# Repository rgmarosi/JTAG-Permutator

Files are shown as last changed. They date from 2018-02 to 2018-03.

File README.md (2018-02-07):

# JTAG-Permutator
A low-cost USB tool for identifying pinouts of possible JTAG programming/debug interfaces on electronics.
<p align="center">
  
  
  
</p>

## License
The JTAG Permutator is an adaptation of the "[JTAGulator](https://github.com/grandideastudio/jtagulator)" designed by Joe Grand of [Grand Idea Studio](http://www.grandideastudio.com/) and is used under the [Creative Commons Attribution 3.0 United States license](https://creativecommons.org/licenses/by/3.0/us/).

The JTAG Permutator design is also distributed under the [Creative Commons Attribution 3.0 United States license](https://creativecommons.org/licenses/by/3.0/us/).

### Major changes from the JTAGulator design
1. Silicon Labs EFM8 microcontroller used instead of Parallax microcontroller with USB-UART bridge IC
2. Target voltage supplied by SC195 buck regulator rather than filtered PWM
3. Removed screw terminals
4. Reduced IO channels from 24 down to 8
5. Used different level translator IC (target voltage range is now 0.8V~3.3V) (to be verified)
6. Reduced board area from 13.6 square inches down to 1.7 square inches

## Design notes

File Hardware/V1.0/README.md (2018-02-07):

# Notes
- IDC headers are not placed in BOM because fab & assembly is cheaper with all SMD components. They can be easily hand-soldered.
- The JTAG Permutator is compatible with [Bus Pirate V3 probes](https://www.seeedstudio.com/Bus-Pirate-v3-probe-Kit-p-526.html) or equivalent.
- The programmer interface requires a stronger 1kOhm pull-up resistor on the reset pin in order for the debug adapter to remain connected to the JTAG Permutator
  - Solder a 1kOhm resistor between TP1 and TP5 on the rear of the board to fix this
- The programmer used with the programmer header is the Silicon Labs [8-bit USB Debug Adapter](https://www.silabs.com/products/development-tools/mcu/8-bit/8bit-mcu-accessories/8-bit-debug-adapter)
  - The programmer header may not be needed if I can figure out how to use the bootloader on the EFM8. Until then, it's there for easy debugging of this first prototype.
- The fab & assembly house I used for this first prototype was [MacroFab](https://macrofab.com/). Another good self-serve fab & assembly house is [PCB:NG](https://www.pcb.ng/).
- I don't yet know if the onboard buck regulator (SC195) output is tri-stated when disabled. I need to test it. For now, don't connect the target power rail to powered targets. Only use it if you're powering the target using the JTAG Permutator.
  - Maximum current output of the buck regulator is ~500mA.
## Pull-up resistor fix
<p align="left">
  
</p>

# Planned changes
1. Pull up C2CK pin of microcontroller to 5V rail using 1kOhm resistor.
2. Remove programming header once bootloader is figured out and firmware is functioning as intended. Keep C2 interface and power rail test points.
3. Add silkscreen pin table for probe cable if space permits.
4. More to come...

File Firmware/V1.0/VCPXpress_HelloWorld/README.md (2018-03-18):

Prints "Hello World!" to a serial console every half second and blinks the "Heartbeat" LED on the board every second.

Have either the [Silicon Labs VCP Drivers](https://www.silabs.com/products/development-tools/software/usb-to-uart-bridge-vcp-drivers) installed on your PC, or have Simplicity Studio IDE installed on your PC to allow communication between your serial terminal and the microcontroller. Any serial terminal configuration should work.

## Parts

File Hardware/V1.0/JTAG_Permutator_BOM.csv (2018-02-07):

Title | JTAG Permutator
Revision | 1
Date | 2/6/2018
Generated | 2/6/2018 16:55
Company
Comment 1 | Robert Marosi
Comment 2 | CC BY 3.0 US
Comment 3
Comment 4
Total Parts | 43
Total Unique Parts | 20
Ref | Qty | Value | Footprint | MFR | MPN | SPN | SPR | DNI
C7 | 1 | 10uF | Capacitors_SMD:C_0603 | TDK Corporation | C1608X5R0J106M080AB | 445-4112-2-ND | Digi-Key
C6 C3 C1 | 3 | 4.7uF | Capacitors_SMD:C_0603 | Murata | GRM188R60J475ME19D | 490-5421-2-ND | Digi-Key
C5 C4 C2 | 3 | 0.1uF | Capacitors_SMD:C_0603 | Murata | GRM188R71E104KA01 | 490-1524-2-ND | Digi-Key
D4 | 1 | LED_ON | LEDs:LED_0603 | Lite-On Inc. | LTST-C190KRKT | 160-1436-2-ND | Digi-Key
D3 | 1 | LED_PWR | LEDs:LED_0603 | Lite-On Inc. | LTST-C190KRKT | 160-1436-2-ND | Digi-Key
D2 | 1 | LED_BOOT | LEDs:LED_0603 | Lite-On Inc. | LTST-C190KRKT | 160-1436-2-ND | Digi-Key
D1 | 1 | LED_Heartbeat | LEDs:LED_0603 | Lite-On Inc. | LTST-C190KRKT | 160-1436-2-ND | Digi-Key
F1 | 1 | 500mA PTC | Fuse_Holders_and_Fuses:Fuse_SMD1206_Reflow | Bel Fuse Inc. | 0ZCJ0050FF2G | 507-1802-1-ND | Digi-Key
L1 | 1 | 1uH | Inductors_SMD:L_0805 | Taiyo Yuden | MBKK2012T1R0M | 587-4156-2-ND | Digi-Key
P3 | 0 | Bus Pirate Probe Cable Connector | Connectors_IDC:IDC-Header_2x05_Pitch2.54mm_Straight | On Shore Technology Inc. | 302-S101 | ED1543-ND | Digi-Key | P3
P2 | 0 | Debug Adapter Connector | Connectors_IDC:IDC-Header_2x05_Pitch2.54mm_Straight | On Shore Technology Inc. | 302-S101 | ED1543-ND | Digi-Key | P2
P1 | 1 | USB_OTG | digikey-footprints:609-4613-1-ND | Amphenol FCI | 10118192-0001LF | 609-4613-1-ND | Digi-Key
R13 | 1 | 200k | Resistors_SMD:R_0603 | TE Connectivity Passive Product | CPF0603F200KC1 | A102235TR-ND | Digi-Key
R22 R23 R1 R2 R3 R4 | 6 | 1k | Resistors_SMD:R_0603 | Panasonic Electronics Components | ERJ-3GEYJ102V | P1.0KGTR-ND | Digi-Key
R5 R6 R7 R8 R9 R10 R11 R12 R14 R15 R16 R17 R18 R19 R20 R21 | 16 | 470R | Resistors_SMD:R_0603 | Yageo | RC0603JR-07470RL | 311-470GRTR-ND | Digi-Key
TP1 TP2 TP3 TP4 TP5 TP6 | 0 | TEST | Measurement_Points:Measurement_Point_Round-SMD-Pad_Small | N/A | N/A | N/A | N/A | TP1 TP2 TP3 TP4 TP5 TP6
U3 | 1 | GTL2003BQ_115 | GTL2003:DHVQFN20 | NXP USA Inc. | GTL2003BQ 115 | 568-4293-1-ND | Digi-Key
U4 | 1 | SC195 | SC195:MLPQ-UT8 | Semtech Corporation | SC195ULTRT | SC195ULTR-ND | Digi-Key
U1 U5 U6 | 3 | DT1446-04V-7 | DT1446-04V-7:SOT563 | Diodes Inc. | DT1446-04V-7 | DT1446-04V-7DITR-ND | Digi-Key
U2 | 1 | EFM8UB31F40G-A | digikey-footprints:24-WQFN_(4x4) | Silicon Labs | EFM8UB31F40G-A-QFN24 | 336-4232-ND | Digi-Key
BOM made with KICAD_BOM_WIZARD (https://github.com/HashDefineElectronics/KiCad_BOM_Wizard.git)
Generated 2/6/2018 4:55:48 PM

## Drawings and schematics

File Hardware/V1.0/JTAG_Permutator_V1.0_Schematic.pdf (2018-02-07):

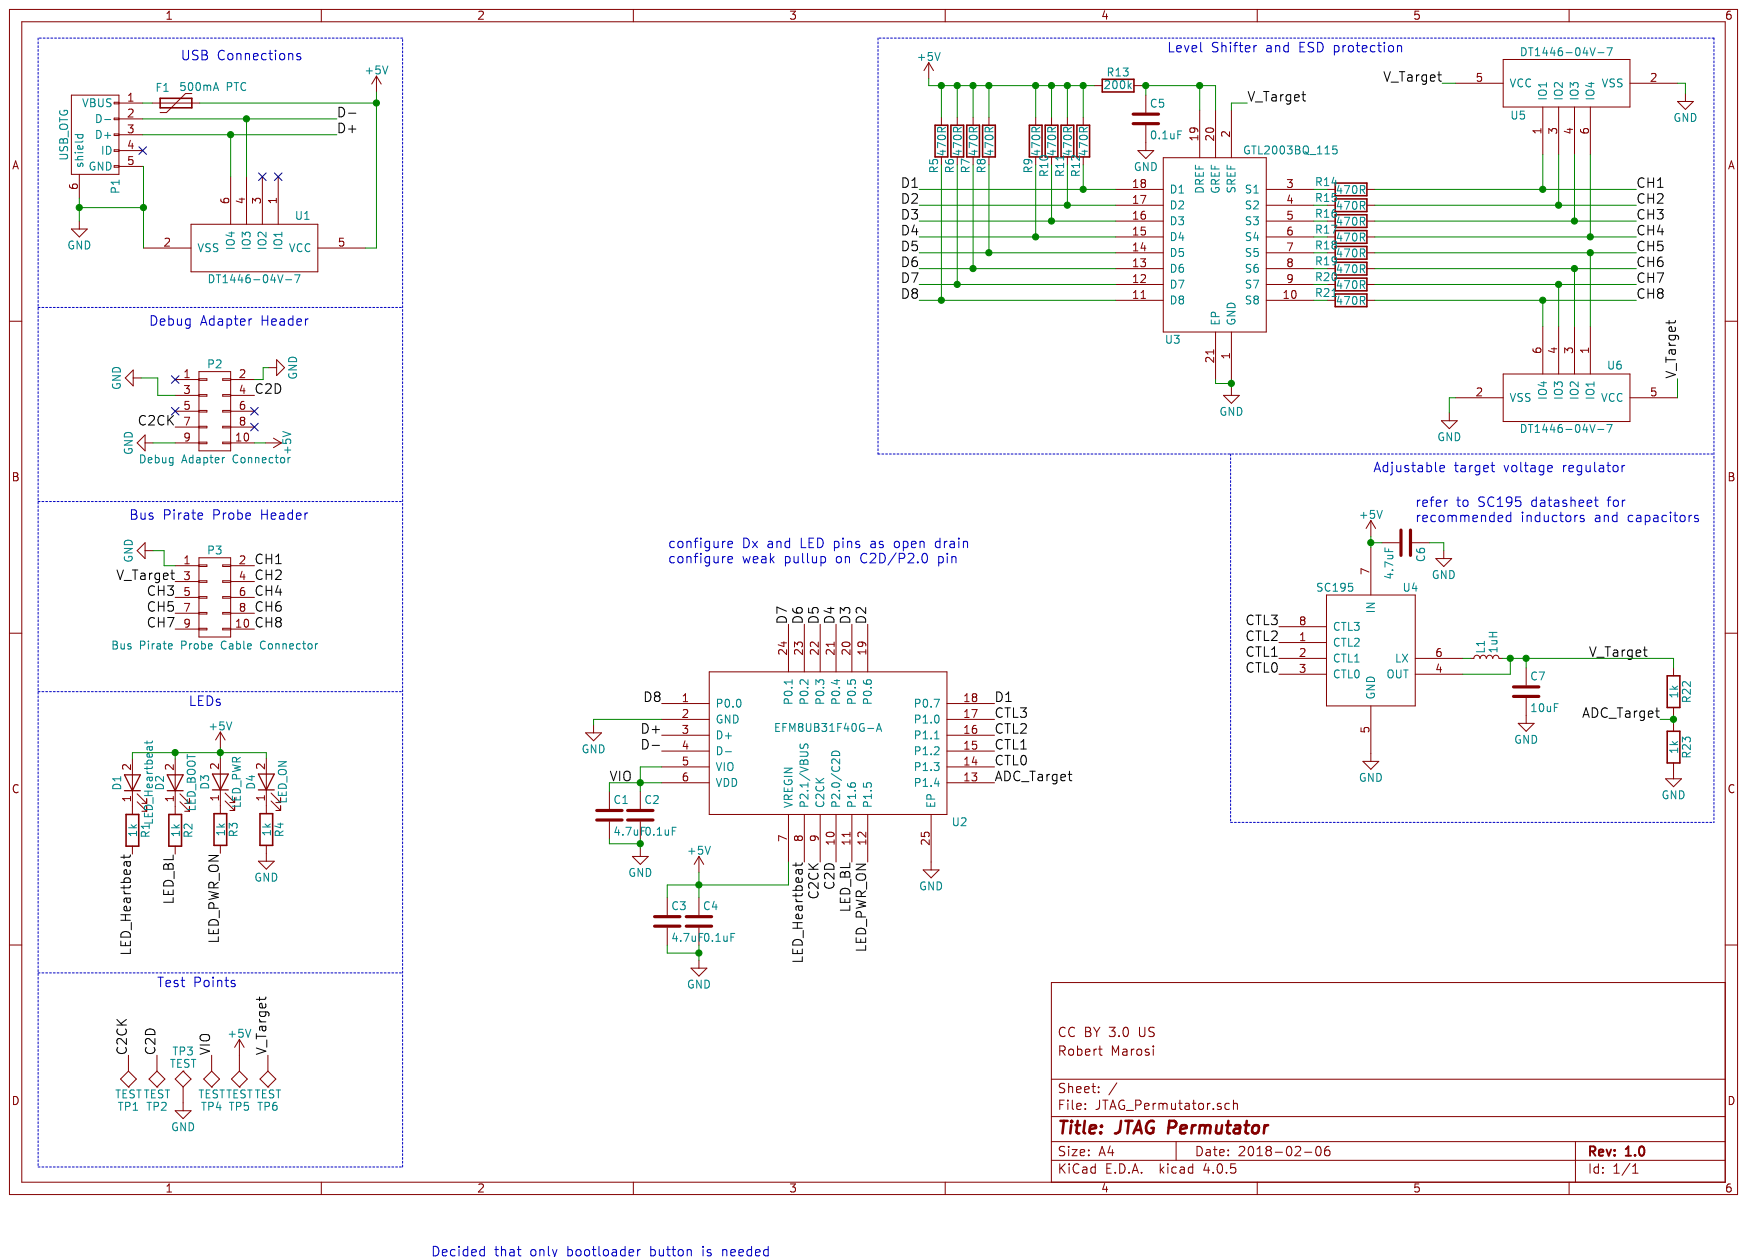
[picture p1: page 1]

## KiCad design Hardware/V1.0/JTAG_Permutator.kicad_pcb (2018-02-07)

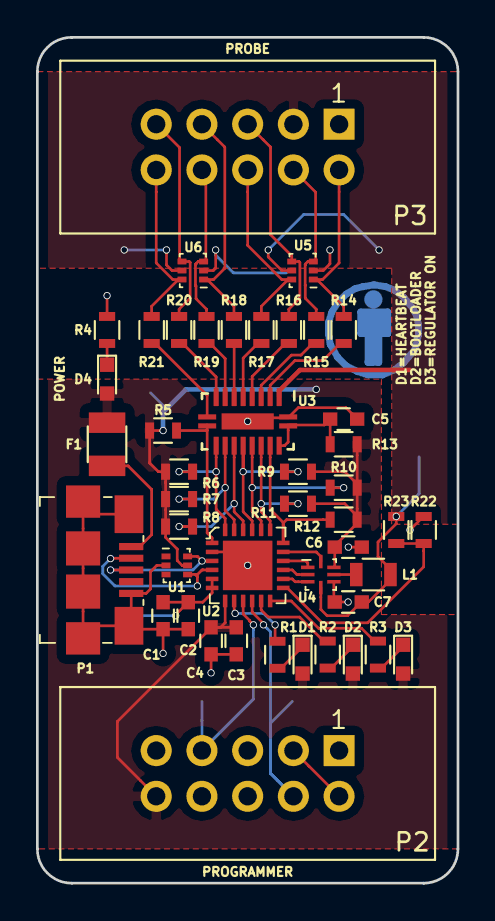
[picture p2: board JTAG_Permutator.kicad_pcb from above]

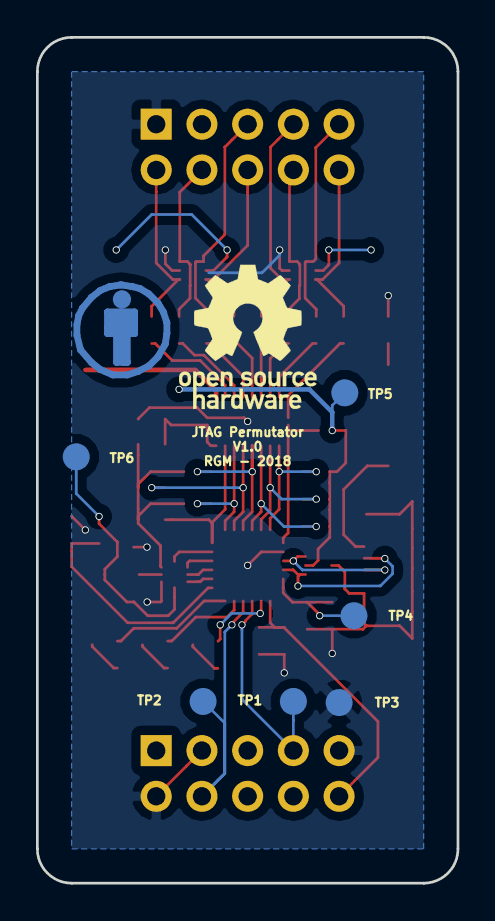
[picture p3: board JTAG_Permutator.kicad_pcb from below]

Board: 2 copper layers, 23.4 x 47.0 mm, 51 parts (6 on the bottom side), 47 nets.

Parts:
C1, C3, C6: 4.7uF; C_0603
C2, C4, C5: 0.1uF; C_0603
C7: 10uF; C_0603
D1: LED_Heartbeat; LED_0603
D2: LED_BOOT; LED_0603
D3: LED_PWR; LED_0603
D4: LED_ON; LED_0603
F1: 500mA PTC; Fuse_SMD1206_Reflow
L1: 1uH; L_0805
P1: USB_OTG; 609-4613-1-ND
P2: Debug Adapter Connector; IDC-Header_2x05_Pitch2.54mm_Straight
P3: Bus Pirate Probe Cable Connector; IDC-Header_2x05_Pitch2.54mm_Straight
R1, R2, R3, R4, R22, R23: 1k; R_0603
R5, R6, R7, R8, R9, R10, R11, R12, R14, R15, R16, R17, R18, R19, R20, R21: 470R; R_0603
R13: 200k; R_0603
TP1, TP2, TP3, TP4, TP5, TP6: TEST; Measurement_Point_Round-SMD-Pad_Small
U1, U5, U6: DT1446-04V-7; SOT563
U2: EFM8UB31F40G-A; 24-WQFN_(4x4)
U3: GTL2003BQ_115; DHVQFN20
U4: SC195; MLPQ-UT8

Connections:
+5V: C3.1, C4.1, C6.2, D1.2, D2.2, D3.2, D4.2, F1.1, P2.10, R5.1, R6.1, R7.1, R8.1, R9.1, R10.1, R11.1, R12.1, R13.1, TP5.1, U1.5, U2.7, U4.7
/ADC_Target: R22.2, R23.1, U2.13
/C2CK: P2.7, TP1.1, U2.9
/C2D: P2.4, TP2.1, U2.10
/CH1: P3.2, R14.1, U5.1
/CH2: P3.4, R15.1, U5.3
/CH3: P3.5, R16.1, U5.4
/CH4: P3.6, R17.1, U5.6
/CH5: P3.7, R18.1, U6.1
/CH6: P3.8, R19.1, U6.3
/CH7: P3.9, R20.1, U6.4
/CH8: P3.10, R21.1, U6.6
/CTL0: U2.14, U4.3
/CTL1: U2.15, U4.2
/CTL2: U2.16, U4.1
/CTL3: U2.17, U4.8
/D1: R12.2, U2.18, U3.18
/D2: R11.2, U2.19, U3.17
/D3: R10.2, U2.20, U3.16
/D4: R9.2, U2.21, U3.15
/D5: R8.2, U2.22, U3.14
/D6: R7.2, U2.23, U3.13
/D7: R6.2, U2.24, U3.12
/D8: R5.2, U2.1, U3.11
/D+: P1.3, U1.6, U2.3
/D-: P1.2, U1.4, U2.4
/LED_BL: R2.2, U2.11
/LED_Heartbeat: R1.2, U2.8
/LED_PWR_ON: R3.2, U2.12
/VIO: C1.1, C2.1, TP4.1, U2.5, U2.6
/V_Target: C7.1, L1.2, P3.3, R22.1, TP6.1, U3.2, U4.4, U5.5, U6.5
GND: C1.2, C2.2, C3.2, C4.2, C5.2, C6.1, C7.2, P1.5, P1.6, P2.2, P2.3, P2.9, P3.1, R4.2, R23.2, TP3.1, U1.2, U2.2, U2.25, U3.1, U3.21, U4.5, U5.2, U6.2
unnamed: C5.1, R13.2, U3.19, U3.20
unnamed: D1.1, R1.1
unnamed: D2.1, R2.1
unnamed: D3.1, R3.1
unnamed: D4.1, R4.1
unnamed: F1.2, P1.1
unnamed: L1.1, U4.6
unnamed: R14.2, U3.3
unnamed: R15.2, U3.4
unnamed: R16.2, U3.5
unnamed: R17.2, U3.6
unnamed: R18.2, U3.7
unnamed: R19.2, U3.8
unnamed: R20.2, U3.9
unnamed: R21.2, U3.10

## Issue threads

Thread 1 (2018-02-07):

Board testing TODO list

rgmarosi, 2018-02-07:
- [ ] blinky test code for all LEDs
  - [ ] verify 24.5MHz oscillator is default, then switch to 48MHz oscillator from now on
  - [ ] verify blink frequency with oscilloscope
  - [ ] figure out source of weak glow for idle LEDs (weak pull-ups? open-drain leakage current?)
- [ ] get USB-serial terminal communication working for ease of debugging
- [ ] buck voltage regulator test code
  - [ ] verify output voltage for all 16 settings
  - [ ] measure output impedance of disabled regulator
- [ ] ADC test code
  - [ ] configure internal voltage reference for 2.4V or 1.65V
  - [ ] measure target voltage rail with ADC (USB debugging and working regulator needed)
- [ ] level shifter IO test code
  - [ ] test output and input of shifter interface (loopback testing might be a good idea)

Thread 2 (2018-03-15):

USB suspend interrupt halts main clock

rgmarosi, 2018-03-15:
Silicon Labs forum post: https://www.silabs.com/community/mcu/8-bit/forum.topic.html/vcp_selective_suspen-yyJC

Discovered while testing modified USB "Echo" demo program. If serial terminal, such as Tera Term or PuTTY is not connected to the JTAG-Permutator via a COM port and that COM port is inactive for >10 seconds, Windows 10 PC will send a `DEV_SUSPEND` USB interrupt to the microcontroller, which stops its main oscillator until woken up by another USB interrupt, such as `DEVICE_OPEN`.

The halted main oscillator was the reason why the timer ISR I had for toggling the heartbeat LED stopped firing after 10 seconds of inactivity on the COM port. Connecting a serial terminal to the unused COM port will cause the main oscillator to resume, allowing for normal behavior.

rgmarosi, 2018-03-15:
No solution is yet available from Silicon Labs to prevent the DEV_SUSPEND USB interrupt from halting the oscillator.

Workaround for Windows 10 PCs: (Prevents Windows from sending suspend interrupt to device)
1. Connect the JTAG-Permutator to the computer
2. Open Device Manager
3. Right click on the Silicon Labs device in the COM port section and select `Properties`
4. In the `Power Management` tab of the properties, uncheck the box for `Allow the computer to turn off this device to save power`

Closed 2018-03-15.

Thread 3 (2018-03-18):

Manufacturer and product descriptor strings don't change

rgmarosi, 2018-03-18:
VID and PID descriptors for microcontroller must be same as default for VCP driver to recognize the microcontroller.
modified manufacturer, product, or serial number strings in `descriptor.c` do not show on the host PC when the microcontroller is connected. Only the default strings are visible on the host PC, such as "Silicon Labs CP210x USB to UART Bridge."

This may be due to the VCP driver. I need to ask again in the forums. Not critical to fix, but the default product string doesn't accurately reflect the function of the microcontroller.

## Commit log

2018-02-07 Uploaded Fab & Assembly Files
    [JTAG_Permutator-B.Cu.gbl, JTAG_Permutator-B.Mask.gbs, JTAG_Permutator-B.Paste.gbp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]
2018-02-07 Update README.md
    Added photos of PCB
2018-02-07 Update README.md
    Added photo with probes
2018-02-07 Update README.md
    added pull-up resistor fix photo
